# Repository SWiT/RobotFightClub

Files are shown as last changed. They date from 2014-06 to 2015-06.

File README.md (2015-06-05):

###Robot Fight Club
Copyright (C) 2015 Matthew Gary Switlik

This program is free software: you can redistribute it and/or modify
it under the terms of the GNU General Public License as published by
the Free Software Foundation, either version 3 of the License, or
(at your option) any later version.

This program is distributed in the hope that it will be useful,
but WITHOUT ANY WARRANTY; without even the implied warranty of
MERCHANTABILITY or FITNESS FOR A PARTICULAR PURPOSE.  See the
GNU General Public License for more details.

You should have received a copy of the GNU General Public License
along with this program.  If not, see <http://www.gnu.org/licenses/>.

###About
Robot Fight Club is an autonomous robot fighting platform. It is built using datamatrices, webcams, Arduinos, Beaglebones, and a Linux PC. The system tracks datamatrix on top of the robot and other objects.  To do this it uses the opencv and dmtx libraries.  The rfcscanner application runs on a Beaglebone Black and scans a video source for the arena edges, if each robot is alive, and its position.  The data is sent over the network to the rfcserver application running on a Linux PC. The rfcserver has a wireless serial connection to each Arduino based robot. Each robot has a balloon that holds down its power button.  When its balloon pops the robot turns off.

The game is simple.  Each robot tries to pop the balloon of the other robots and be the last alive.

We are currently back in alpha stages.  The old python code didn't scale and was too sensitive for changing lighting conditions. The current Beaglebone Black based solution has one BBB running rfcscanner per 4'x6' arena section so it will scale very well.  By using C++ instead of Python the OpenCV libraries should give better control of camera focus and exposure along with a reduced footprint.

###You will need:
A PC Running Ubuntu 14.04 or your preferred Linux Distribution.
A webcam capable of 1080p or higher resolution.
A printed set of datamatrices (the arena corners C0-C3 and two digit numbers 00-03).
A Beaglebone Black with 4GB+ of storage (8GB+ Recommended).

###Setup rfcserver (Linux PC)
Install the following packages (Ubuntu):
````
sudo apt-get install git v4l2ucp  git  gcc-avr avr-libc openjdk-7-jre build-essential checkinstall cmake pkg-config yasm libtiff4-dev libjpeg-dev libjasper-dev libavcodec-dev libavformat-dev libswscale-dev libdc1394-22-dev  libxine-dev libgstreamer0.10-dev libgstreamer-plugins-base0.10-dev libv4l-dev python-dev python-numpy  libtbb-dev libqt4-dev libgtk2.0-dev libdmtx-utils libdmtx-dev blueman
````

Install the lastest opencv package (3.0+):
```
cd ~
git clone https://github.com/Itseez/opencv.git
cd opencv && mkdir release && cd release
cmake -D CMAKE_BUILD_TYPE=RELEASE -D CMAKE_INSTALL_PREFIX=/usr/local -D BUILD_NEW_PYTHON_SUPPORT=ON -D BUILD_EXAMPLES=ON ..
make
sudo make install
```

Install the Arduino IDE. http://arduino.cc/en/Main/Software

Give permission for the Arduino IDE to access the serial ports:
```
sudo adduser $USER dialout
```

Download or Clone the RobotKnifeFight code from github:
```
cd ~
git clone https://github.com/SWiT/RobotFightClub.git
cd RobotFightClub
```

Compile rfcserver (optional)
```
g++ -W -Wall rfcserver.cpp -o rfcserver -lopencv_core -lopencv_highgui -lopencv_imgproc
```

Run rfcserver:
```
./rfcserver
```

###Setup rfcscanner (Beaglebone Black)
Download and install the latest Debian image from http://beagleboard.org/latest-images
This guide has been tested with the Debian 4GB 2015-03-01 release.

There are a few things that need to be tweaked once the image is running on a BBB.

Set a password, set the hostname (rfc_bbb#),Set the timezone, and add an alias for 'll',
```
passwd
nano /etc/hostname
sudo dpkg-reconfigure tzdata
echo 'alias ll="ls -la"' >> ~/.bash_aliases
sudo reboot
```

Grow the partition (optional)
```
cd /opt/scripts/tools
git pull
sudo ./grow_partition.sh
sudo reboot
```

Update and install prerequisites.
```
sudo apt-get update && sudo apt-get -y upgrade && sudo apt-get -y dist-upgrade
sudo apt-get -y purge libopencv-dev
sudo rm /usr/lib/libopencv_*
sudo apt-get -y install build-essential cmake pkg-config libtiff4-dev libjpeg-dev libjasper-dev libpng12-dev libavcodec-dev libavformat-dev libswscale-dev libv4l-dev libdmtx-dev libgtk2.0-dev
sudo reboot
```

Build and Install OpenCV (This takes a few hours)
```
git clone https://github.com/Itseez/opencv.git
cd opencv && mkdir build && cd build
cmake -D CMAKE_BUILD_TYPE=RELEASE -D CMAKE_INSTALL_PREFIX=/usr/local -D WITH_CUDA=OFF -D WITH_OPENCL=OFF -D BUILD_opencv_apps=OFF -D BUILD_DOCS=OFF -D BUILD_PERF_TESTS=OFF -D BUILD_TESTS=OFF -D ENABLE_NEON=on -D BUILD_NEW_PYTHON_SUPPORT=ON ..
make
sudo make install
sudo ldconfig
cd ~
```

Build and run rfcscanner
```
git clone https://github.com/SWiT/RobotFightClub.git
cd RobotFightClub
g++ rfcscanner.cpp -o rfcscanner -lopencv_core -lopencv_videoio -lopencv_imgcodecs -ldmtx
./rfcscanner [RFCSERVER_IP]
```

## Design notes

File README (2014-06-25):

Robot Fight Club Arena v0.11 (master)

Robot Fight Club Arena is a platform built using Python 2.7+, Arduino v1.5.6-r2 BETA, OpenCV 2.4.9+, and dmtx 0.7.4.  It scans video sources for data matrices and status LEDs to determine the arena edges, if each robot is alive, and its position.  The data is sent out via serial radios to each Arduino robot.  Each robot has a balloon that holds down its power button.  When its balloon pops the robot turns off.

The game is simple.  Each robot tries to pop the balloon of the other robots and be the last alive.

We are currently in Beta stages.  Positioning works but could use optimizations.  

This guide will walk you through setting up an arena for Robot Fight Club.

You will need:
    a PC Running Ubuntu 14.04 or your preferred Linux Distribution.
    a webcam capable of 1080p or higher resolution.
    the printed datamatrices

Install the following packages (Ubuntu):
    sudo apt-get install git v4l2ucp  git  gcc-avr avr-libc openjdk-7-jre build-essential checkinstall cmake pkg-config yasm libtiff4-dev libjpeg-dev libjasper-dev libavcodec-dev libavformat-dev libswscale-dev libdc1394-22-dev  libxine-dev libgstreamer0.10-dev libgstreamer-plugins-base0.10-dev libv4l-dev python-dev python-numpy  libtbb-dev libqt4-dev libgtk2.0-dev libdmtx-utils libdmtx-dev blueman

Install pydmtx:
    cd ~
    git clone https://github.com/dmtx/dmtx-wrappers.git
    cd dmtx-wrappers/python
    sudo python setup.py install

Install the lastest opencv package (2.4.8+):
    cd ~
    git clone https://github.com/Itseez/opencv.git
    cd opencv
    git checkout -b 2.4 origin/2.4
    mkdir release
    cd release
    cmake -D CMAKE_BUILD_TYPE=RELEASE -D CMAKE_INSTALL_PREFIX=/usr/local ..
    make
    sudo make install

Install Arduino 1.5.6-r2 BETA or later:
    http://arduino.cc/en/Main/Software

Give permission for the Arduino IDE to access the serial ports:
    sudo adduser $USER dialout

Download or Clone the RobotKnifeFight code from github:
    git clone git@github.com:SWiT/RobotFightClubArena.git

Run the Arena server:
    cd RobotKnifeFight
    python rfcarena.py

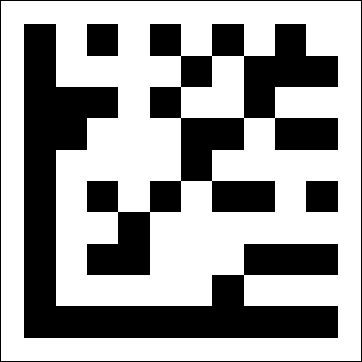
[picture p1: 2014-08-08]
datamatrices/C3.png

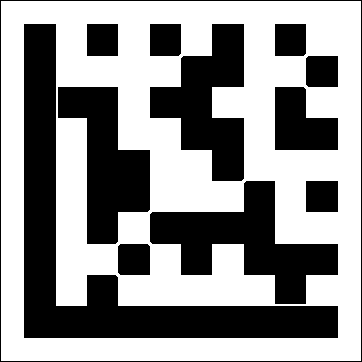
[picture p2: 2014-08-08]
datamatrices/C1_stencil.png

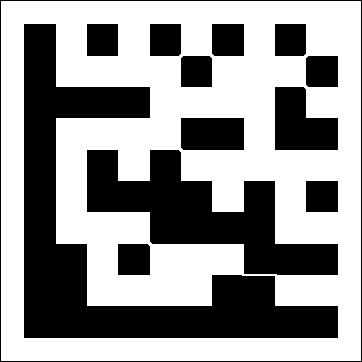
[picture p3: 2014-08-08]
datamatrices/C7_stencil.png

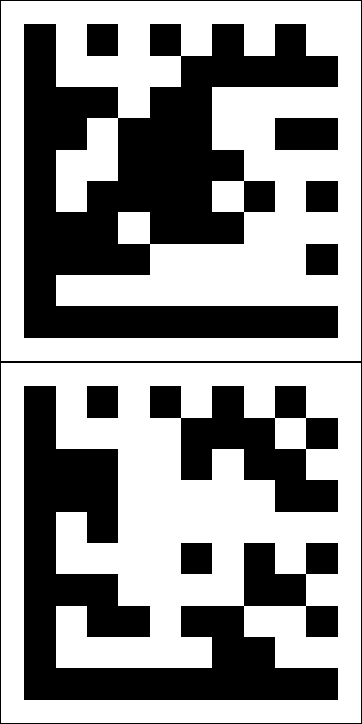
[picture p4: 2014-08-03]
datamatrices/C4-5.png

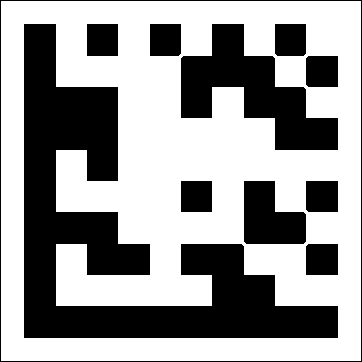
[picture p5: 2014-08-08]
datamatrices/C5_stencil.png

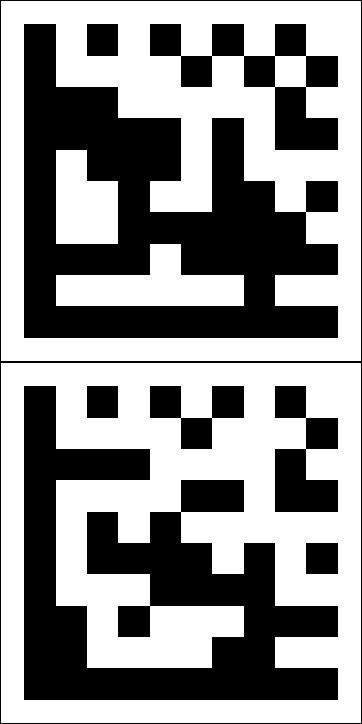
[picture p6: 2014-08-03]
datamatrices/C6-7.png

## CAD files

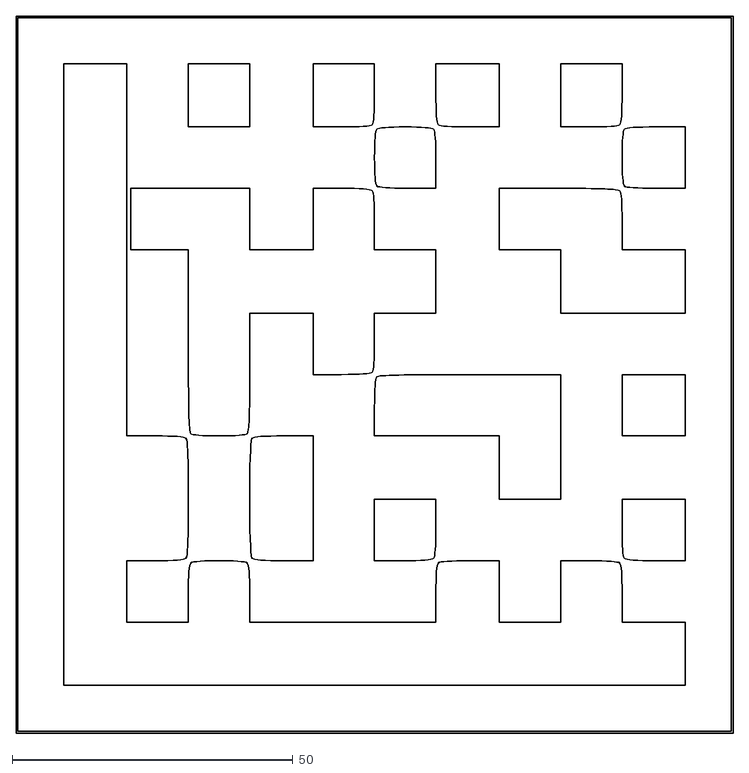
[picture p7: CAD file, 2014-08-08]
datamatrices/C2_stencil.dxf
127.7 x 127.7

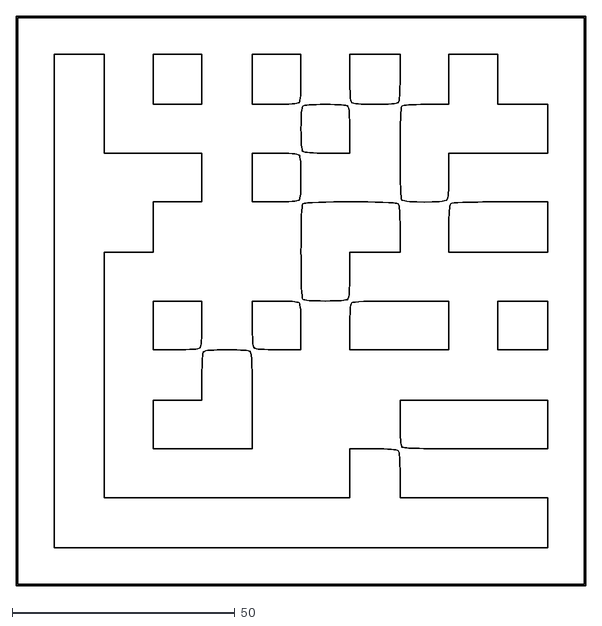
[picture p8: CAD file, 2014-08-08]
datamatrices/C3_stencil.dxf
127.7 x 127.7

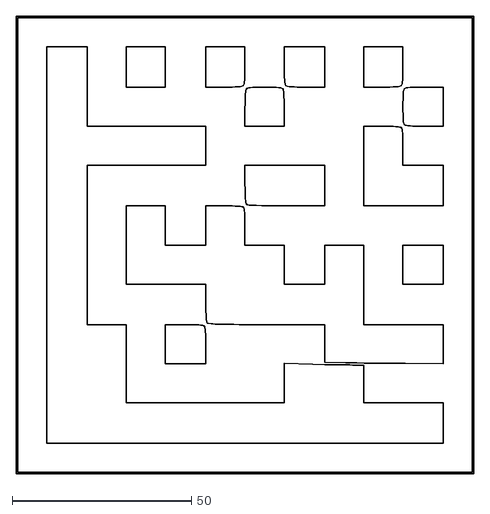
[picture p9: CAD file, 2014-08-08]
datamatrices/C7_stencil.dxf
127.7 x 127.7

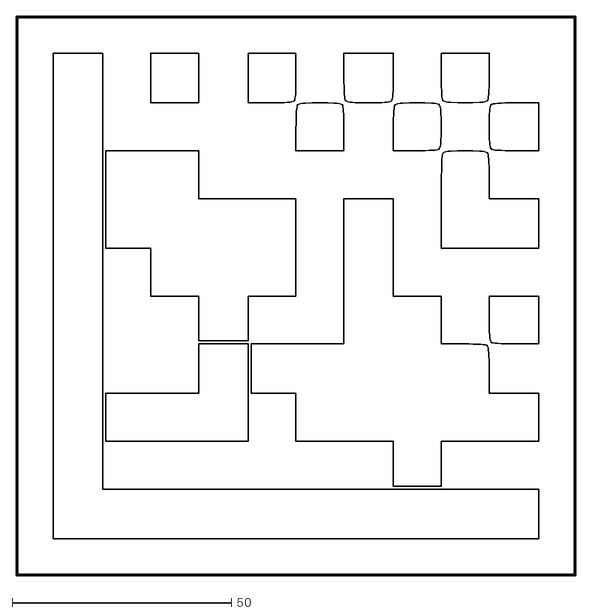
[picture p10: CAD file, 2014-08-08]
datamatrices/C6_stencil.dxf
127.7 x 127.7

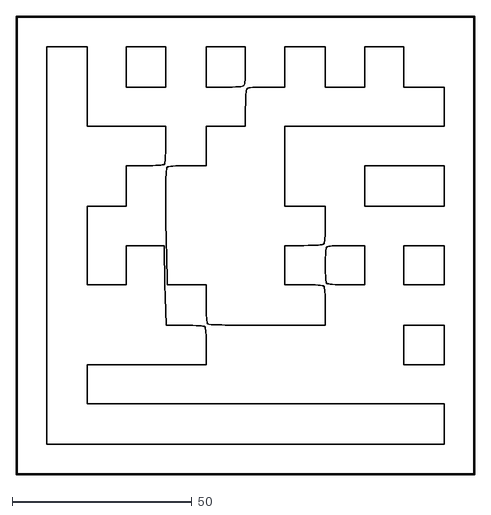
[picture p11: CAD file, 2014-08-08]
datamatrices/C4_stencil.dxf
127.7 x 127.7

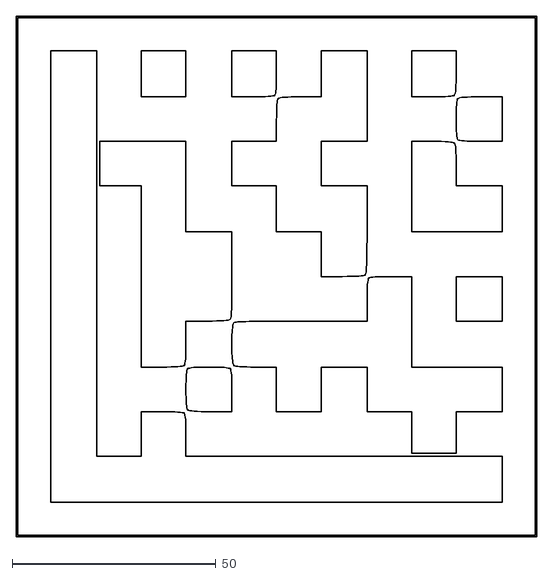
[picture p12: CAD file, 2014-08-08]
datamatrices/C1_stencil.dxf
127.7 x 127.7

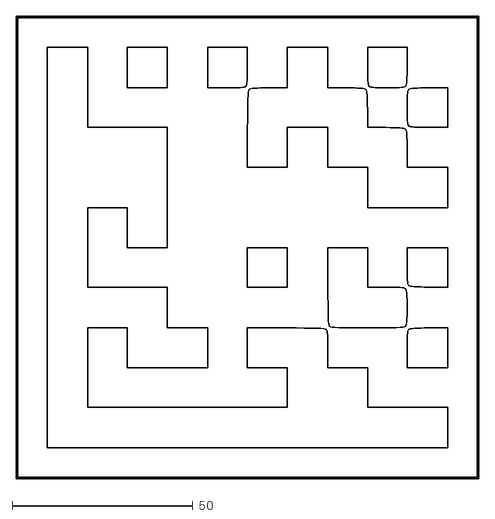
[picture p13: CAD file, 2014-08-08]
datamatrices/C5_stencil.dxf
127.7 x 127.7

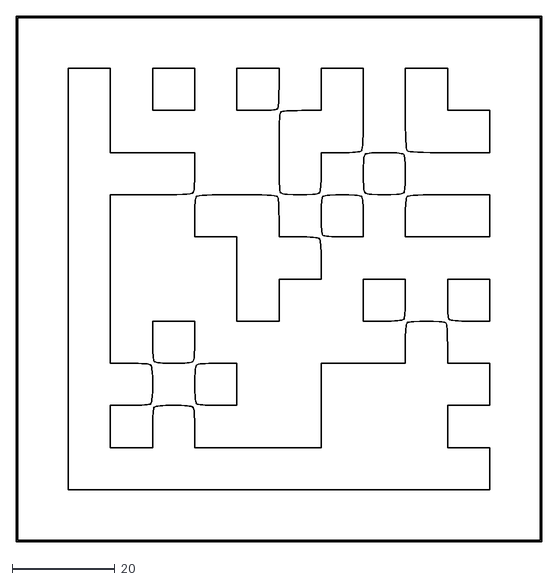
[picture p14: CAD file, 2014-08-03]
datamatrices/C0_stencil.dxf
102.2 x 102.2

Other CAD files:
knifebot/Assembled_Bot.skp
knifebot/Flat_Pack.skp

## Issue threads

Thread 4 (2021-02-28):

You should fix your readme

LeSnake04, 2021-02-28:
you have to put a space between the `#` and the header:
###Robot Fight Club Copyright (C) 2015 Matthew Gary Switlik →
### Robot Fight Club Copyright (C) 2015 Matthew Gary Switlik

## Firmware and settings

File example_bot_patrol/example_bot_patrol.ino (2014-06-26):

#include "bot_id.h"
#include "pin_defs.h"
#include <Servo.h>

Servo LeftDrive, RightDrive;
#define LEFT_FWD 180
#define LEFT_STOP 90
#define LEFT_REV 0
#define RIGHT_FWD 0
#define RIGHT_STOP 90
#define RIGHT_REV 180
byte speed_L = LEFT_STOP;
byte speed_R = RIGHT_STOP;
unsigned long timeLastServoUpdate = 0;
unsigned long timeToStop = 0;
unsigned long timeToGo = 0;
unsigned long timeLastOutput = 0;

unsigned long timeLastMessage = 0;

String serialInputString = "";  // a string to hold incoming data

int Me[3] = {0,0,0};
int Target[3] = {0,0,0};
int Bot[4][5] = {{0,0,0,0,0},{0,0,0,0,0},{0,0,0,0,0},{0,0,0,0,0}}; //{x, y, heading, alive, teamid}


int headingTo = 0;
byte distanceTo = 0;
byte rotAmountTo = 0;
byte actionCount = 0;

boolean gameOn = false;

byte DestIndex = 255;
int Destinations[4][2] = {{8,8},{8,38},{62,38},{62,8}};

/*
  Setup
------------------------------------------------------------------------------*/
void setup(){
  LeftDrive.attach(LEFT_DRIVE_PIN);
  RightDrive.attach(RIGHT_DRIVE_PIN);
  pinMode(BUMP_SWITCH_RIGHT_PIN, INPUT);
  pinMode(BUMP_SWITCH_LEFT_PIN, INPUT);
  pinMode(STATUS_LED_PIN, OUTPUT);
  
  LeftDrive.write(LEFT_STOP);
  RightDrive.write(RIGHT_STOP);
  
  serialInputString.reserve(114); //28 per bot + 1 for the end char.
  Serial.begin(115200);
  Serial.println("\nexample_bot: patrol");
}


/* 
  Main loop
------------------------------------------------------------------------------*/
void loop(){
  
  
  processSerialInput();
  
  //"Thought processes"
  //-------------------------------------------
  
  
  if(gameOn){
    
    if(Me[0]>0 || Me[1]>0){  //if my position is valid.
      if(DestIndex==255){
        DestIndex = whatPosClosest(Me);
      }
    
      //what is the distance to the Target point?
      distanceTo = distance(Me, Target);
      
      //what is the heading to the Target point?
      headingTo = bearing(Me, Target); //int(16 + round( -Me.bearing(Target)/(PI/8) + (PI/16) ))%16; //convert the bearing to a heading of 0-15 increasing counter clockwise
      
      //if farther than 8 inches to Target
      if(distanceTo > 8 ){
        
        //what is the rotation direction and amount needed?
        int hdiff = (headingTo-Me[2]);
        if (hdiff==0){
          //I'm facing the right way to the Target point
          rotAmountTo = 0;
          if(timeToStop == 0 and timeToGo<millis()){
            //drive towards it.
            speed_L = throttle(LEFT_FWD, LEFT_STOP, 1.0);
            speed_R = throttle(RIGHT_FWD, RIGHT_STOP, 1.0);
            timeToStop = millis() + (1000*distanceTo/8);
            timeToGo = timeToStop + 900;
            actionCount++;
          }
        }else if (hdiff < -180 || (0 < hdiff && hdiff < 180)){
          //Turn left
          rotAmountTo = (360+abs(hdiff))%360;
          if (rotAmountTo > 0){
            //turn left then wait a little bit
            if(timeToStop == 0 and timeToGo < millis()){
              speed_L = throttle(LEFT_REV, LEFT_STOP, 0.1);
              speed_R = throttle(RIGHT_FWD, RIGHT_STOP, 0.1);
              timeToStop = millis() + (2*rotAmountTo);
              timeToGo = timeToStop + 900;
              actionCount++;
            }
          }
          
        }else{
          //Turn right
          rotAmountTo = (360-abs(hdiff))%360;
          if (rotAmountTo > 0){
            //turn right then wait a little bit
            if(timeToStop == 0 and timeToGo < millis()){
              speed_L = throttle(LEFT_FWD, LEFT_STOP, 0.1);
              speed_R = throttle(RIGHT_REV, RIGHT_STOP, 0.1);
              timeToStop = millis() + (2*rotAmountTo);
              timeToGo = timeToStop + 900;
              actionCount++;
            }
          }
        }
      }else{
        //withinrange of the current destination, set the nest one.
        DestIndex = (DestIndex+1)%4;
        Target[0] = Destinations[DestIndex][0];
        Target[1] = Destinations[DestIndex][1];
      }
      
    } //end valid Me position
    
    
    
  } //end game on
  
  
  //-------------------------------------------
  
  
  //Is it time to stop?  I consider this more of a reflex than thought.
  if(timeToStop > 0 && millis() >= timeToStop){
    Stop();
  }
  
  //if a bump switch is triggered backup
  if(!digitalRead(BUMP_SWITCH_RIGHT_PIN) || !digitalRead(BUMP_SWITCH_LEFT_PIN)){
    speed_L = LEFT_REV;
    speed_R = RIGHT_REV;
    timeToStop = millis() + 500;
    timeToGo = timeToStop + 1000;
  }
    
  //Update Servo positions  
  if(millis() - timeLastServoUpdate > 15){  //limit servo updating to every 15ms at most
    LeftDrive.write(speed_L);
    RightDrive.write(speed_R);
    timeLastServoUpdate = millis();
  }
  
  //Output various statuses and values once in a while.
  if(millis()-timeLastOutput > 3000){
    outputStatus();
    timeLastOutput = millis();
  }
  
  delay(1);
}
/*----------------------------------------------------------------------------*/


void Stop(){
  speed_L = LEFT_STOP;
  speed_R = RIGHT_STOP;
  timeToStop = 0;
  
  if(timeToGo <= millis()){
    actionCount = 0;
  }
}

int throttle(int Direction, int Stop, float Throttle){
  return int((Direction-Stop)*Throttle + Stop);
}

int distance(int pt0[], int pt1[]) {
  return sqrt(pow(pt1[0]-pt0[0],2)+pow(pt1[1]-pt0[1],2));
}

int bearing(int pt0[], int pt1[]) {
  return atan2((pt1[1] - pt0[1]),(pt1[0] - pt0[0]))*180/PI;
}

byte whatPosClosest(int p0[]){
  int p1[2] = {0,0};
  byte index = 0;
  byte closest = 255;
  for(byte i=0; i<4; i++){
    p1[0] = Destinations[i][0];
    p1[1] = Destinations[i][1];
    byte d = distance(p0, p1);
    if(d < closest){
      closest = d;
      index = i;
    }
  }
  return index;
}

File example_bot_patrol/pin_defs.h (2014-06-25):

//pin 0 - serial reserved for uploading and debugging radio.
//pin 1 - serial reserved
#define BUMP_SWITCH_LEFT_PIN 2
#define LEFT_DRIVE_PIN 3
#define BUMP_SWITCH_RIGHT_PIN 4
#define RIGHT_DRIVE_PIN 5
//pin 6 not currently used
//pin 7 not currently used
//pin 8 not currently used
//pin 8 not currently used
//pin 9 not currently used
//pin 10 not currently used
//pin 10 not currently used
//pin 12 not currently used
#define STATUS_LED_PIN 13

//A0 not currently used
//A1 not currently used
//A2 not currently used
//A3 not currently used
//A4 not currently used
//A5 not currently used

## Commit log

2012-04-10 Optical flow fedd inital point from good points to track by accident.
2012-04-25 added arduino robot test code
2012-05-24 set number of bots. adjustable led threshold.
2013-06-27 added knifebot, started gunbot
    [4 x AA batteries in holder.skp, 4AA_battery.skp, Arduino Duemilanove.skp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]
2013-06-28 3d files for gunbot
    [base.skp, pan_bracket1.skp, pan_bracket2.skp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]
2013-07-03 more gunbot
    [Assembled.skp, base.skp]
2013-07-03 gunbot flat_pack
    [Assembled.skp, Flat_Pack.skp, base.skp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]
2013-07-04 trimmed side corners, tweaks to assembled and flatpack
    [Assembled.skp, Flat_Pack.skp, servo.skp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]
2013-07-06 Sketchup 2013, shorten length, lasercut file
    [Assembled.skp, Flat_Pack.skp, Flat_Pack_2D.dxf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]
2013-07-06 FLAT PACK 2D DXF
    [Assembled.skp, Flat_Pack.skp, Flat_Pack_2D.dxf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]
2013-07-06 FIXED PAN BRACKET
    [Assembled.skp, Flat_Pack.skp, Flat_Pack_2D.dxf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]
2013-07-16 post laser cut update
    [Assembled.skp, base.skp, pan_bracket1.skp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]
2013-07-16 update flatpack, where did DXF export go?
    [Flat_Pack.skp, Flat_Pack_2D.skp]
2013-07-16 exported updated DXF
    [Flat_Pack_2D.dxf]
2013-08-06 enclosed electronics
    [Assembled.skp, Flat_Pack_2D.dxf, Flat_Pack_2D.skp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]
2013-08-07 next version v0.02 of gunbot, not flat packed yet
    [Gunbot_Assembled.skp, base.skp, front_side.skp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]
2013-08-07 raising balloon kill switch
    [Gunbot_Assembled.skp, base.skp, rear_side.skp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]
2013-08-08 raised balloon kill switch
    [Gunbot_Assembled.skp, base.skp, support.skp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]
2013-08-09 raised symbol, killswitch is now vertical, wood feet, wood pin holder, improved hole sizes and placement
    [Assembled_Bot.skp, Flat_Pack.skp, arm.skp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]
2013-08-09 new balloon support, arm changes
    [Assembled_Bot.skp, arm.skp, balloon_support.skp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]
2013-08-09 flat packed
    [Assembled_Bot.skp, Flat_Pack.skp, Knifebot_Flat_Pack_2D.skp]
2013-08-09 EXPORTED FLATPACKS
    [Gunbot_Flat_Pack.skp, Gunbot_Flat_Pack_2D.dxf, Gunbot_Flat_Pack_2D.skp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]
2013-08-12 knifebot revisions
    [Assembled_Bot.skp, Flat_Pack.skp, balloon_support.skp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]
2013-08-17 knifebot improvements
    [Assembled_Bot.skp, Flat_Pack.skp, Knifebot_Flat_Pack_2D.skp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]
2013-10-03 knife bot v1.0 gunbot v0.51
    [Assembled_Bot.skp, Gunbot_Assembled.skp, Temp_flatpack.dxf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]
2014-02-09 mount holes for arduino and beaglebone
    [4 x AA batteries in holder.skp, Arduino Duemilanove.skp, Arduino_UNO_R3.skp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]
2014-02-27 cambot 3d camera pan and tilt
    [box_bottom.skp, box_front.skp, box_side.skp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]
2014-03-09 deleting junk
    [Temp_flatpack.dxf]
2014-03-10 upped diameter for batteries for the beaglebone
    [4AA_battery_holder.skp, Micro_Switch.skp, arm_mount.skp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]
2014-03-10 wheel changes: max bearing depth
    [cambot_assembled.skp, wheel_18.skp, wheel_support01.skp]
2014-03-10 fixed balloon support
    [balloon_support2.skp]
2014-03-11 knifebot and cambot changes
    [cambot_assembled.skp, cambot_wheelset_fp.dxf, cambot_wheelset_fp.skp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]
2014-03-13 knifebot post cut fixes
    [balloon_support2.skp, bottom_plate.skp, cambot_assembled.skp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]
2014-03-17 post TEDx OU changes
    [bottom_plate.skp, bumper_guide0.skp, bumper_guide1.skp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]
2014-03-27 knifebot killswitch and servo models, started stackbot
    [4AA_battery.skp, 4AA_battery_holder.skp, Arduino_UNO_R3.skp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]
2014-03-28 added stackbot flat pack
    [arm2.skp, arm_mount.skp]
2014-03-28 renamed some parts. started 25 unit flatpack
    [Balloon.skp, Stackbot_50pack_gluedparts2.skp, arm_pin_holder.skp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]
2014-03-29 Set stackbot thicknesses to 5mm
    [Balloon.skp, Raspberry_Pi_-_Model_B_Rev.skp, Stackbot_50pack_gluedparts2.skp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]
2014-03-31 30 pack
    [Stackbot_30pack_3_46x30.skp, Stackbot_30pack_4_46x32.skp]
2014-04-04 removed dead symbol mount holes. Data matrices!
    [arm_pin_holder.skp, plate_bottom.skp, plate_controller.skp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]
2014-04-11 raised symbol plate etc
    [arm.skp, arm_v2.skp, plate_bottom.skp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]
2014-04-20 fixes for new parts
    [arm_v2.skp, arm_v2_4ws.skp, bumper_guide0.skp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]
2014-04-22 LED hole in plate_balloon
    [plate_balloon.skp]
2014-04-26 added balloon support
    [balloon_support.skp, plate_controller.skp]
2014-04-27 removed arduino transmitter code, and knifebot model
    [4AA_battery_holder.skp, Arduino_UNO_R3.skp, Assembled_Bot.stl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]
2014-04-27 raise kill switch .1"
    [switch_mount0.skp, switch_mount1.skp]
2014-05-01 fixed bump_guard
    [bump_guard.skp]
2014-05-29 thesholding for detecting the led
2014-06-07 added video device and resolution selection to GUI
2014-06-09 getting lists of devices, getting ready to add BT serial selection
2014-06-18 added more corner datamatrix for multiple camera support
2014-06-19 define things by number of zones instead of video devices or total POI
2014-06-20 video device and zone selection
2014-06-25 handle error from no video devices.
2014-07-24 fixes, fix scope of serial devices
2014-07-31 2 corners per page and a stencil attempt
    [C0_stencil.dxf]
2014-08-06 DM Corner stencils
    [C1_stencil.dxf, C2_stencil.dxf, C3_stencil.dxf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]
2014-08-06 C0-C3 are the wrong size.
    [C0_stencil.dxf, C1_stencil.dxf, C2_stencil.dxf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]
2014-08-07 finished resizing C0-C3
    [C0_stencil.dxf, C1_stencil.dxf, C2_stencil.dxf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]
2014-08-11 print when not found
2015-04-06 moved sketch up models to bitsync.
    [4AA_battery_holder.skp, Arduino_UNO_R3.skp, Balloon.skp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]
2015-09-10 removed ctrl-C signal handling since it doesn't work with blocking socket calls.
2015-09-29 trying to use an array of socket connections.
